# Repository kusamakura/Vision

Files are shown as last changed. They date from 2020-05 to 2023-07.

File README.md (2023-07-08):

# Vision Alt PCB

A PCB for the [Vision keyboard by SatT Keyboards](https://github.com/satt99/Vision) with alternative layout options.

## Notable changes

- R2 2U Backspace
- Left bottom row: from 2U-1U to 1U-2U, add 3U
- Right bottom row: remove 1U-1.75U, add 2.75U
- Nudge P position 0.125 mm to the left

## Layout

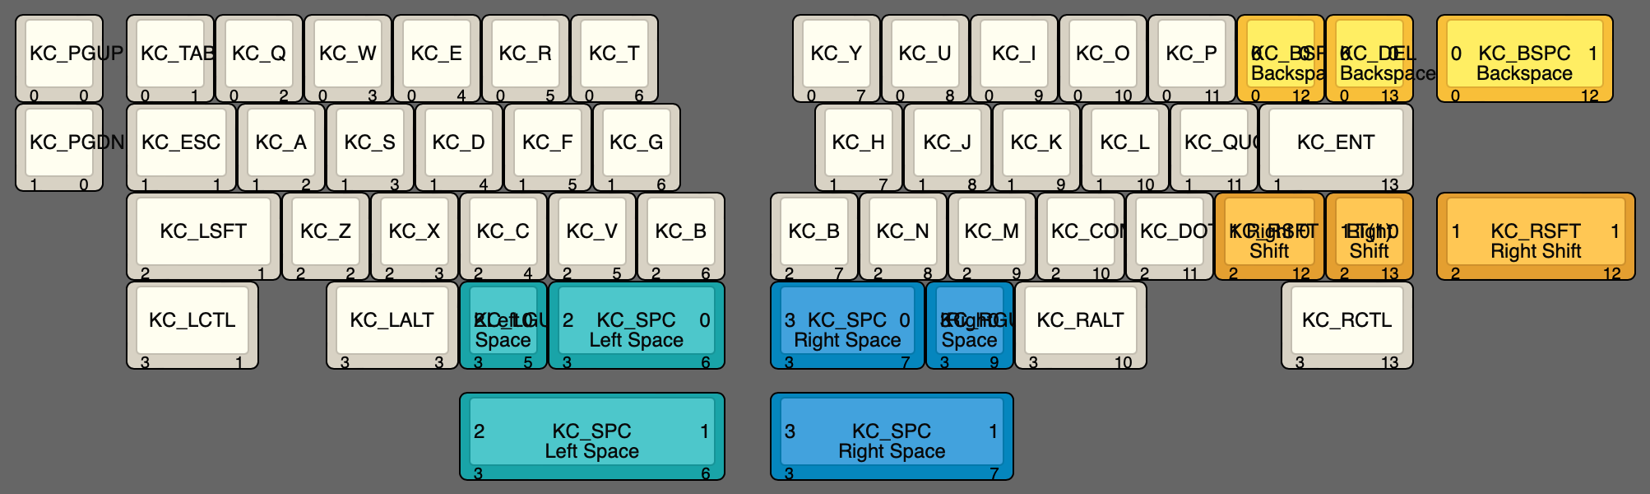
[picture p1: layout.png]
Layout


## How to use

Use the gerbers, BOM, and CPL files in the [JLCPCB production files folder](./JLCPCB/production_files/). **Set the PCB thickness to 1.2 mm when ordering**; otherwise your PCB will not work with the case.

Prototypes pending to check if this works.

The source files were originally in KiCAD 5, converted to KiCAD 6, then modified.
JLC production output was generated with the [JLC Fabrication Toolkit plugin](https://github.com/bennymeg/JLC-Plugin-for-KiCad).

## Disclaimer

Maintainers and contributors are not liable if you end up with a non-functional PCB. Order at your own risk. Support will not be provided but pull requests will be reviewed and possibly accepted.

## Todo

- [x] Finalize layout changes
- [x] Order prototypes
- [ ] Confirm prototypes
- [ ] Order plates
- [ ] Write firmware

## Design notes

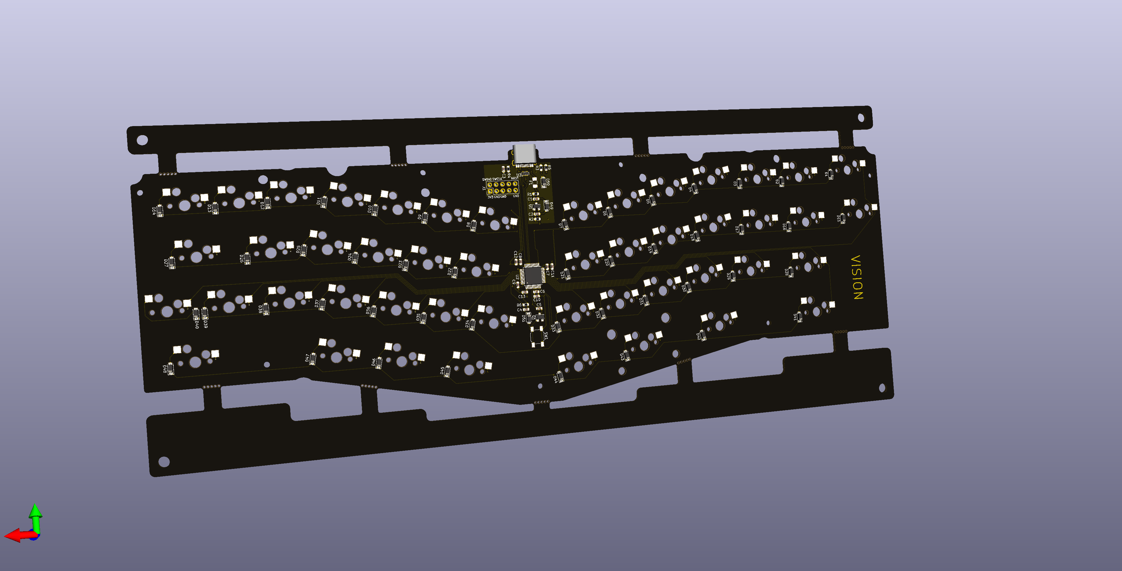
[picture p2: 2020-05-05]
Renders/Vision.png

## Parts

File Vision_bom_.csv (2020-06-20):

Component | Description | Part | References | Value | Footprint | Quantity Per PCB | Datasheet
1 | Unpolarized capacitor, small symbol | C_Small | C7 C8 C9 C13 | 100nF | C_0603_1608Metric | 4
2 | Unpolarized capacitor, small symbol | C_Small | C6 | 10nF | C_0603_1608Metric | 1
3 | Unpolarized capacitor, small symbol | C_Small | C4 | 10uF | C_0603_1608Metric | 1 | ~
4 | Unpolarized capacitor, small symbol | C_Small | C1 C2 C10 | 1uF | C_0603_1608Metric | 3 | ~
5 | Unpolarized capacitor, small symbol | C_Small | C3 | 4.7nF | C_0603_1608Metric | 1 | ~
6 | Unpolarized capacitor, small symbol | C_Small | C5 C11 C12 | 4.7uF | C_0603_1608Metric | 3 | ~
7 | Diode, small symbol | D_Small | D1 D2 D3 D4 D5 D6 D7 D8 D9 D10 D11 D12 D13 D14 D15 D16 D17 D18 D19 D20 D21 D22 D23 D24 D25 D26 D27 D28 D29 D30 D31 D32 D33 D34 D35 D36 D37 D38 D39 D40 D41 D42 D43 D44 D45 D46 D47 D48 D51 | 1N4148W | D_SOD-123 | 49
8 | Schottky diode, small symbol | D_Schottky_Small | D49 | BAT41ZFILM | D_SOD-123 | 1 | ~
9 | Bidirectional transient-voltage-suppression diode | D_TVS | D50 | SMF9.0CA | D_SOD-123 | 1 | ~
10 | Resettable fuse, polymeric positive temperature coefficient, small symbol | Polyfuse_Small | F1 | 500mA | Fuse_1206_3216Metric | 1
11 | Cortex Debug Connector, standard ARM Cortex-M SWD and JTAG interface | Conn_ARM_JTAG_SWD_10 | J1 | Conn_ARM_JTAG_SWD_10 | PinHeader_2x05_P2.54mm_Vertical | 1 | http://infocenter.arm.com/help/topic/com.arm.doc.ddi0314h/DDI0314H_coresight_components_trm.pdf
12 | Digital NPN Transistor, 2k2/47k, SOT-23 | DTC123J | Q1 | DTC123J | SOT-23 | 1
13 | Resistor, small symbol | R_Small | R1 R2 R6 | 100k | R_0603_1608Metric | 3 | ~
14 | Resistor, small symbol | R_Small | R4 | 1M | R_0603_1608Metric | 1 | ~
15 | Resistor, small symbol | R_Small | R3 R5 | 5.1k | R_0603_1608Metric | 2
16 | Push button switch, generic, two pins | SW_Push | SW1 | SW_Push | SW_SPST_SKQG_WithoutStem | 1
17 | 250mA Low Quiscent Current LDO, 3.0V output, SOT-23 | MCP1700-3002E_SOT23 | U1 | MCP1700-3002E_SOT23 | SOT-23 | 1 | http://ww1.microchip.com/downloads/en/DeviceDoc/20001826C.pdf
18 | ARM Cortex-M0 MCU, 128KB flash, 16KB RAM, 48MHz, 2-3.6V, 37 GPIO, LQFP-48 | STM32F072CBTx | U2 | STM32F072CBUx | LQFP-48_7x7mm_P0.5mm | 1 | http://www.st.com/st-web-ui/static/active/en/resource/technical/document/datasheet/DM00090510.pdf
19 |  | TPD4E05U06DQAR | U3 | TPD4E05U06DQAR | USON-TPDxE05U06 | 1
20 |  | HRO-TYPE-C-31-M-12 | USB1 | HRO-TYPE-C-31-M-12 | HRO-TYPE-C-31-M-12-Assembly | 1
Component Groups: | 20
Component Count: | 78
Fitted Components: | 78
Number of PCBs: | 1
Total components: | 78
Schematic Version:
Schematic Date:
PCB Variant: | default
BoM Date: | 2020/06/13 17:00:34
Schematic Source: | Vision.sch
KiCad Version: | Eeschema (5.1.4)-1

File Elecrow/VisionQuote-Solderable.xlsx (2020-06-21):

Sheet: PCB Specification
Vision PCB Solderable Specification
PCB Quantity | 30pcs
Layer | 2layer
PCB Thickness | 1.2mm
Dimensions | 299.5 mm * 124.3 mm
Castellated Hole | No
PCB Color | Black
Surface Finish | Immersoin gold
Copper Weight | 1oz
Text Color | White
Different Design | 1
Please find more PCB information on our on-line PCB ordering Page
https://www.elecrow.com/pcb-manufacturing.html

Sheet: BOM
VISION PCB
# | Reference | QTY | Value | Package | Manufacturer Part number | Description | SMD | THT | Original | Elecrow PN | Note | LCSC Link | Digikey Link | KBDFans Link
1 | C7 C8 C9 C13 | 4 | 100nF | C_0603_1608Metric | GCM188R71H104KA57D | Ceramic Capacitor | 8 |  | Y |  |  | https://lcsc.com/product-detail/Multilayer-Ceramic-Capacitors-MLCC-SMD-SMT_muRata_GCM188R71H104KA57D_100nF-104-10-50V-Car-level_C85864.html
2 | C6 | 1 | 10nF | C_0603_1608Metric | GRM188R71H103KA01D | Ceramic Capacitor | 2 |  | Y |  |  | https://lcsc.com/product-detail/Multilayer-Ceramic-Capacitors-MLCC-SMD-SMT_muRata_GRM188R71H103KA01D_10nF-103-10-50V_C77053.html
3 | C4 | 1 | 10uF | C_0603_1608Metric | GRM188R61E106KA73D | Ceramic Capacitor | 2 |  | Y |  |  | https://lcsc.com/product-detail/Others_Murata-Electronics-GRM188R61E106KA73D_C344022.html
4 | C1 C2 C10 | 3 | 1uF | C_0603_1608Metric | GRM188R61H105KAALD | Ceramic Capacitor | 6 |  | Y |  |  | https://lcsc.com/product-detail/Multilayer-Ceramic-Capacitors-MLCC-SMD-SMT_muRata_GRM188R61H105KAALD_1uF-105-10-50V_C77386.html
5 | C3 | 1 | 4.7nF | C_0603_1608Metric | GCJ188R71H472KA01D | Ceramic Capacitor | 2 |  | Y |  |  | https://lcsc.com/product-detail/Others_Murata-Electronics-GCJ188R71H472KA01D_C354387.html
6 | C5 C11 C12 | 3 | 4.7uF | C_0603_1608Metric | GRM188R61E475KE15D | Ceramic Capacitor | 6 |  | Y |  |  | https://lcsc.com/product-detail/Multilayer-Ceramic-Capacitors-MLCC-SMD-SMT_Murata-Electronics-GRM188R61E475KE15D_C408137.html
7 | D49 | 1 | BAT41ZFILM | D_SOD-123 | BAT41ZFILM | Diode, standard or schottky | 2 |  | Y |  |  | https://lcsc.com/product-detail/Schottky-Barrier-Diodes-SBD_STMicroelectronics-BAT41ZFILM_C222251.html
8 | D50 | 1 | SMF9.0CA | D_SOD-123 | SMF9.0CA | Bidirectional transient-voltage-suppression diode | 2 |  | Y |  |  | https://lcsc.com/product-detail/TVS_MDD-Microdiode-Electronics-SMF9-0CA_C123799.html
9 | D1 D2 D3 D4 D5 D6 D7 D8 D9 D10 D11 D12 D13 D14 D15 D16 D17 D18 D19 D20 D21 D22 D23 D24 D25 D26 D27 D28 D29 D30 D31 D32 D33 D34 D35 D36 D37 D38 D39 D40 D41 D42 D43 D44 D45 D46 D47 D48 D51 | 49 | SOD-123 | D_SOD-123 | 1N4148W | Diode, standard or schottky | 98 |  | Y |  |  | https://lcsc.com/product-detail/Switching-Diode_ST-Semtech-1N4148W_C81598.html
10 | F1 | 1 | 500mA | Fuse_1206_3216Metric | 1206L050/15YR | PTC Polyfuse Resettable, 500mA Hold, 1A Trip | 2 |  | Y |  |  | https://lcsc.com/product-detail/PTC-Resettable-Fuses_Littelfuse-1206L050-15YR_C151162.html
12 | Q1 | 1 | DTC123J | SOT-23 | DTC123JKAT146 | Digital NPN Transistor, 2k2/47k, SOT-23 | 3 |  | Y |  |  | https://lcsc.com/product-detail/Transistors-NPN-PNP_ROHM-Semicon-DTC123JKAT146_C111724.html
13 | R1 R2 R6 | 3 | 100k | R_0603_1608Metric | ESR03EZPJ104 | Resistor | 6 |  | Y |  |  | https://lcsc.com/product-detail/Others_ROHM-Semicon_ESR03EZPJ104_ROHM-Semicon-ESR03EZPJ104_C253331.html
14 | R4 | 1 | 1M | R_0603_1608Metric | ESR03EZPJ105 | Resistor | 2 |  | Y |  |  | https://lcsc.com/product-detail/Others_ROHM-Semicon_ESR03EZPJ105_ROHM-Semicon-ESR03EZPJ105_C253332.html
15 | R3 R5 | 2 | 5.1k | R_0603_1608Metric | ERJ3RBD5101V | Resistor | 4 |  | Y |  |  | https://lcsc.com/product-detail/Chip-Resistor-Surface-Mount_PANASONIC-ERJ-3RBD5101V_C191782.html
16 | SW1 | 1 | SW_Push | SKQGADE010 | SKQGADE010 | 5.2mm SMD Push Button, 4 pads | 4 |  | Y |  |  | https://lcsc.com/product-detail/Tactile-Switches_ALPS-Electric-SKQGADE010_C116647.html
17 | U1 | 1 | MCP1700-3002E_SOT23 | SOT-23 | MCP1700T-3002E/TT | 250mA Low Quiscent Current LDO, 3.0V output, SOT-23 | 3 |  | Y |  |  | https://lcsc.com/product-detail/Low-Dropout-Regulators-LDO_Microchip-Tech-MCP1700T-3002E-TT_C62244.html
18 | U2 | 1 | STM32F072CBT6 | LQFP-48_7x7mm_P0.5mm | STM32F072CBT6 | STM32F072CBT6 (LQFP-48, 0.5mm Pitch) | 48 |  | Y |  | IF parts are not in stock at LCSC, use Digi-key | https://lcsc.com/product-detail/ST-Microelectronics_STMicroelectronics-STM32F072CBT6_C81720.html | https://www.digikey.jp/product-detail/ja/stmicroelectronics/STM32F072CBT6/497-14645-ND/4815292
19 | U3 | 1 | TPD4E05U06DQAR | 10-USON | TPD4E05U06DQAR | ESD Protection Diode Package | 10 |  | Y |  |  | https://lcsc.com/product-detail/Diodes-ESD_Texas-Instruments_TPD4E05U06DQAR_Texas-Instruments-Texas-Instruments-TPD4E05U06DQAR_C138714.html
20 | USB1 | 1 | HRO-TYPE-C-31-M-12 | HRO-TYPE-C-31-M-12-Assembly | TYPE-C-31-M-12 | USB Type-C Connector | 12 | 4 | Y |  |  | https://lcsc.com/product-detail/USB-Connectors_Korean-Hroparts-Elec-TYPE-C-31-M-12_C165948.html
 | Declare：
 | 1、If the component should be original like Digi-key or Mouser，the component must have complete Manufacture part number

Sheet: Parts Mapping
Please see file VISION_PCB_PRINT.pdf

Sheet: Position File
Please see file vision-bottom.pos

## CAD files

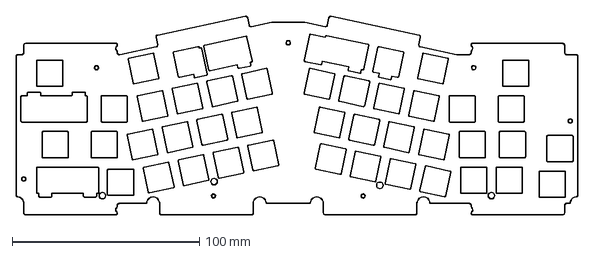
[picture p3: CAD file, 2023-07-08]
plate/alt-plate-noeafspring.dxf
300.2 x 106.1 mm

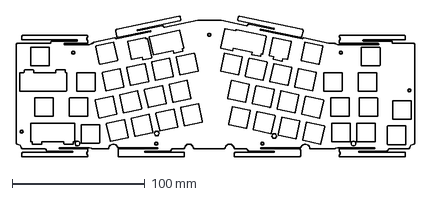
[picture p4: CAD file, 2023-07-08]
plate/alt-plate-leafspring.dxf
300.2 x 106.1 mm

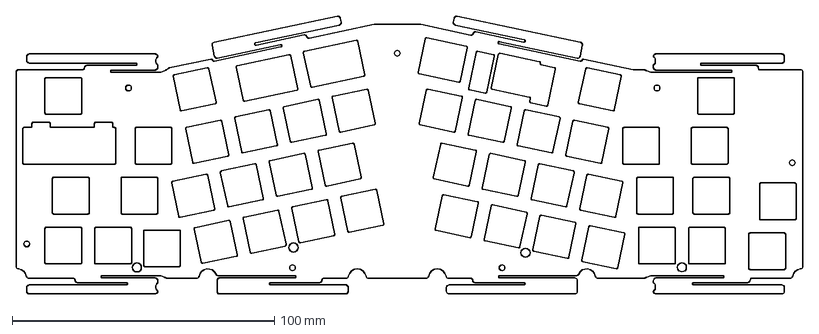
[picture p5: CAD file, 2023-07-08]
plate/og-plate-leafspring-r2.dxf
300.2 x 106.1 mm

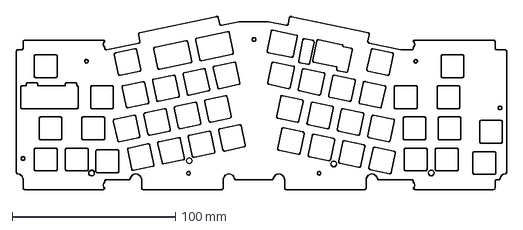
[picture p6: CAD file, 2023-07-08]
plate/og-plate-noleafspring-r2.dxf
300.2 x 106.1 mm

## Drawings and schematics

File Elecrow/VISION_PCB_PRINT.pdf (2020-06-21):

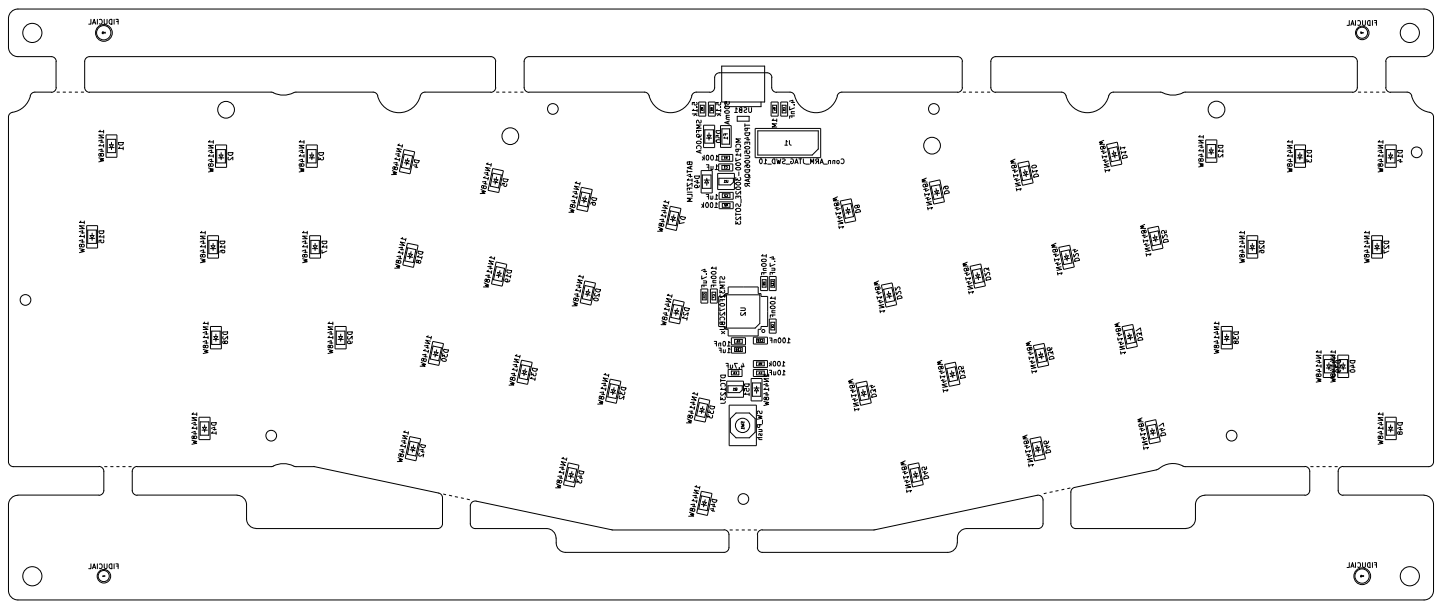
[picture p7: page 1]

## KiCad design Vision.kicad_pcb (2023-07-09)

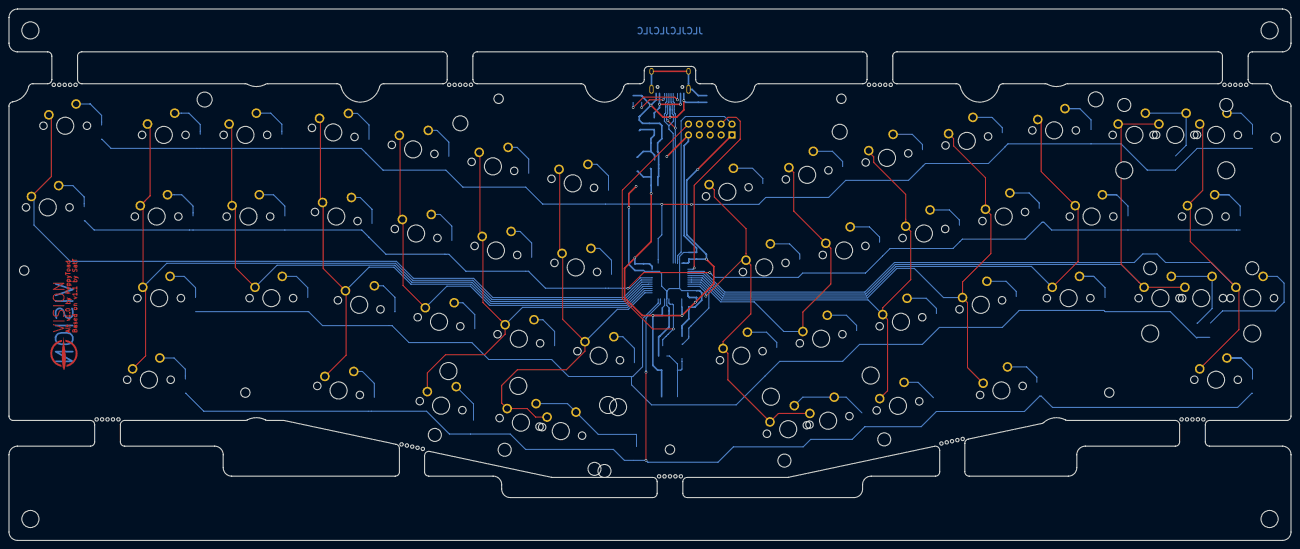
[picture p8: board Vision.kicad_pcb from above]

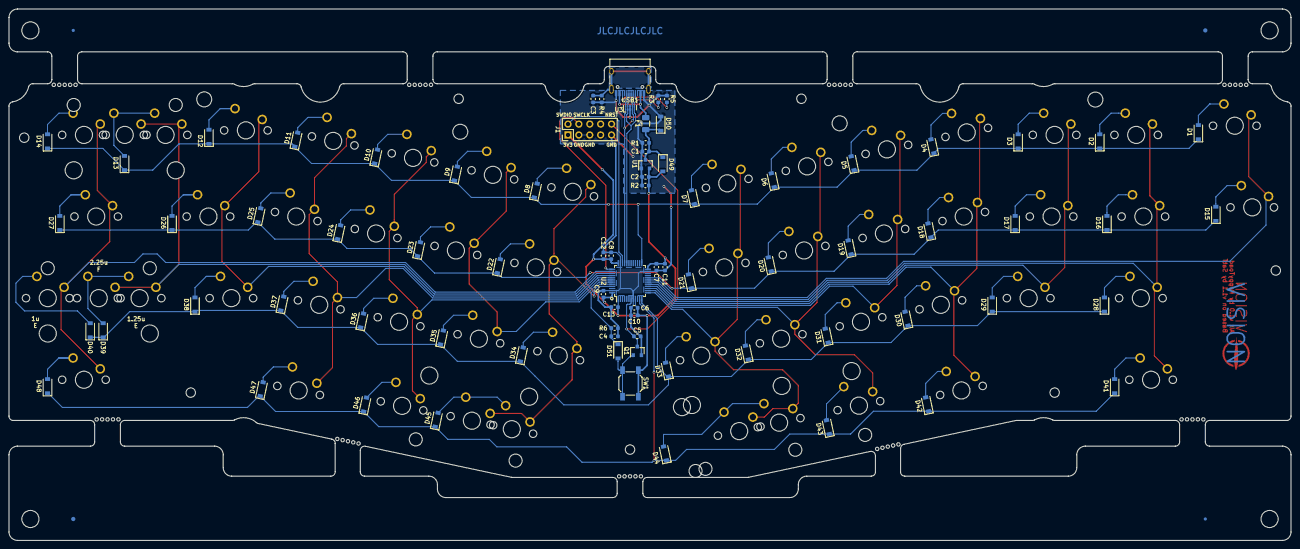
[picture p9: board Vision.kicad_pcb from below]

Board: 2 copper layers, 299.2 x 124.0 mm, 145 parts (83 on the bottom side), 77 nets.

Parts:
C1, C2, C10: 1uF; C_0603_1608Metric
C3: 4.7nF; C_0603_1608Metric
C4: 10uF; C_0603_1608Metric
C5, C11, C12: 4.7uF; C_0603_1608Metric
C6: 10nF; C_0603_1608Metric
C7, C8, C9, C13: 100nF; C_0603_1608Metric
D1, D2, D3, D4, D5, D6, D7, D8, D9, D10, D11, D12, D13, D14, D15, D16, D17, D18, D19, D20, D21, D22, D23, D24, D25, D26, D27, D28, D29, D30, D31, D32, D33, D34, D35, D36, D37, D38, D39, D40, D41, D42, D43, D44, D45, D46, D47, D48, D51: 1N4148W; D_SOD-123
D49: BAT41ZFILM; D_SOD-123
D50: SMF9.0CA; D_SOD-123
F1: 500mA; Fuse_1206_3216Metric
H1: LOGO1; logo1
H2: LOGO2; logo2
H3, H4: FIDUCIAL; Fiducial_0.75mm_Mask2.25mm
H5, H6: FIDUCIAL; Fiducial_1mm_Mask3mm
H7, H8, H9, H10, H11, H12, H13, H14, H15: MOUSEBITES; breakaway-mousebites
J1: Conn_ARM_JTAG_SWD_10; PinHeader_2x05_P2.54mm_Vertical
K_,1: MX-1U; MXOnly-1U-NoLED
K_.1: MX-1U; MXOnly-1U-NoLED
K_;1: MX-1U; MXOnly-1U-NoLED
K_A1: MX-1U; MXOnly-1U-NoLED
K_ALT1, K_ALT2: MX-1.5U; MXOnly-1.5U-NoLED
K_B1, K_B2: MX-1U; MXOnly-1U-NoLED
K_BSPC1: MX-1U; MXOnly-1U-NoLED
K_BSPC2: MX-2U; MXOnly-2U-NoLED
K_C1: MX-1U; MXOnly-1U-NoLED
K_CTRL1, K_CTRL2: MX-1.5U; MXOnly-1.5U-NoLED
K_D1: MX-1U; MXOnly-1U-NoLED
K_DEL1: MX-1U; MXOnly-1U-NoLED
K_E1: MX-1U; MXOnly-1U-NoLED
K_ENTER1: MX-1.75U; MXOnly-1.75U-NoLED
K_ESC1: MX-1U; MXOnly-1U-NoLED
K_F1: MX-1U; MXOnly-1U-NoLED
K_FN1: MX-1U; MXOnly-1U-NoLED
K_G1: MX-1U; MXOnly-1U-NoLED
K_H1: MX-1U; MXOnly-1U-NoLED
K_I1: MX-1U; MXOnly-1U-NoLED
K_J1: MX-1U; MXOnly-1U-NoLED
K_K1: MX-1U; MXOnly-1U-NoLED
K_L1: MX-1U; MXOnly-1U-NoLED
K_M1: MX-1U; MXOnly-1U-NoLED
K_N1: MX-1U; MXOnly-1U-NoLED
K_O1: MX-1U; MXOnly-1U-NoLED
K_P1: MX-1U; MXOnly-1U-NoLED
K_PGDN1: MX-1U; MXOnly-1U-NoLED
K_PGUP1: MX-1U; MXOnly-1U-NoLED
K_Q1: MX-1U; MXOnly-1U-NoLED
K_R1: MX-1U; MXOnly-1U-NoLED
K_S1: MX-1U; MXOnly-1U-NoLED
K_SHIFT1: MX-1.75U; MXOnly-1.75U-NoLED
K_SHIFT2: MX-1.25U; MXOnly-1.25U-NoLED
K_SHIFT3: MX-2.25U; MXOnly-2.25U-NoLED
K_SPC1: MX-2U; MXOnly-2U-ReversedStabilizers-NoLED
K_SPC2: MX-1.75U; MXOnly-1.75U-NoLED
K_SPC3: MX-3U; MXOnly-3U-ReversedStabilizers-NoLED
K_SPC4: MX-2.75U; MXOnly-2.75U-ReversedStabilizers-NoLED
K_T1: MX-1U; MXOnly-1U-NoLED
K_TAB1: MX-1.25U; MXOnly-1.25U-NoLED
K_U1: MX-1U; MXOnly-1U-NoLED
K_V1: MX-1U; MXOnly-1U-NoLED
K_W1: MX-1U; MXOnly-1U-NoLED
K_WIN1, K_WIN2: MX-1U; MXOnly-1U-NoLED
K_X1: MX-1U; MXOnly-1U-NoLED
K_Y1: MX-1U; MXOnly-1U-NoLED
K_Z1: MX-1U; MXOnly-1U-NoLED
Q1: DTC123J; SOT-23
R1, R2, R6: 100k; R_0603_1608Metric
R3, R5: 5.1k; R_0603_1608Metric
R4: 1M; R_0603_1608Metric
SW1: SW_Push; SW_SPST_SKQG_WithoutStem
U1: MCP1700-3002E_SOT23; SOT-23
U2: STM32F072CBUx; LQFP-48_7x7mm_P0.5mm
U3: TPD4E05U06DQAR; USON-TPDxE05U06
USB1: HRO-TYPE-C-31-M-12; USB_C_Receptacle_HRO_TYPE-C-31-M-12

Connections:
+3V3: C2.1, C6.1, C7.1, C8.1, C9.1, C10.1, C11.1, C12.1, C13.1, D49.2 (A), J1.1 (VTref), R2.2, SW1.1, U1.2 (VO), U2.1 (VBAT), U2.9 (VDDA), U2.24 (VDD), U2.36 (VDDIO2), U2.48 (VDD)
+5V: C1.1, D49.1 (K), D50.1 (A1), F1.1, R1.2, U1.3 (VI)
BOOT0: C4.1, D51.1 (K), R6.2, U2.44 (BOOT0)
COL0: K_PGDN1.1 (COL), K_PGUP1.1 (COL), U2.19 (PB1)
COL1: K_CTRL1.1 (COL), K_ESC1.1 (COL), K_SHIFT1.1 (COL), K_TAB1.1 (COL), U2.18 (PB0)
COL2: K_A1.1 (COL), K_Q1.1 (COL), K_Z1.1 (COL), U2.17 (PA7)
COL3: K_ALT1.1 (COL), K_S1.1 (COL), K_W1.1 (COL), K_X1.1 (COL), U2.16 (PA6)
COL4: K_C1.1 (COL), K_D1.1 (COL), K_E1.1 (COL), U2.15 (PA5)
COL5: K_F1.1 (COL), K_R1.1 (COL), K_V1.1 (COL), K_WIN1.1 (COL), U2.14 (PA4)
COL6: K_B1.1 (COL), K_G1.1 (COL), K_SPC1.1 (COL), K_SPC3.1 (COL), K_T1.1 (COL), U2.13 (PA3)
COL7: K_B2.1 (COL), K_H1.1 (COL), K_SPC2.1 (COL), K_SPC4.1 (COL), K_Y1.1 (COL), U2.45 (PB8)
COL8: K_J1.1 (COL), K_N1.1 (COL), K_U1.1 (COL), U2.43 (PB7)
COL9: K_I1.1 (COL), K_K1.1 (COL), K_M1.1 (COL), K_WIN2.1 (COL), U2.42 (PB6)
COL10: K_,1.1 (COL), K_ALT2.1 (COL), K_L1.1 (COL), K_O1.1 (COL), U2.41 (PB5)
COL11: K_.1.1 (COL), K_;1.1 (COL), K_P1.1 (COL), U2.40 (PB4)
COL12: K_BSPC1.1 (COL), K_BSPC2.1 (COL), K_SHIFT2.1 (COL), K_SHIFT3.1 (COL), U2.39 (PB3)
COL13: K_CTRL2.1 (COL), K_DEL1.1 (COL), K_ENTER1.1 (COL), K_FN1.1 (COL), U2.38 (PA15)
D+: U2.33 (PA12), U3.1 (D1+), U3.4 (D2+), U3.7 (NC), U3.10 (NC)
D-: U2.32 (PA11), U3.2 (D1-), U3.5 (D2-), U3.6 (NC), U3.9 (NC)
GND: C1.2, C2.2, C3.1, C4.2, C5.2, C6.2, C7.2, C8.2, C9.2, C10.2, C11.2, C12.2, C13.2, D50.2 (A2), J1.3 (GND), J1.5 (GND), J1.9 (GNDDetect), Q1.2 (E), R1.1, R2.1, R3.1, R4.1, R5.1, R6.1, U1.1 (GND), U2.8 (VSSA), U2.23 (VSS), U2.35 (VSS), U2.47 (VSS), U3.3 (GND), U3.8 (GND)
NRST: C5.1, J1.10 (~RESET), Q1.3 (C), U2.7 (NRST)
unnamed: C3.2, R4.2, USB1.S1
unnamed: D1.2 (A), K_PGUP1.2 (ROW)
unnamed: D2.2 (A), K_ESC1.2 (ROW)
unnamed: D3.2 (A), K_Q1.2 (ROW)
unnamed: D4.2 (A), K_W1.2 (ROW)
unnamed: D5.2 (A), K_E1.2 (ROW)
unnamed: D6.2 (A), K_R1.2 (ROW)
unnamed: D7.2 (A), K_T1.2 (ROW)
unnamed: D8.2 (A), K_Y1.2 (ROW)
unnamed: D9.2 (A), K_U1.2 (ROW)
unnamed: D10.2 (A), K_I1.2 (ROW)
unnamed: D11.2 (A), K_O1.2 (ROW)
unnamed: D12.2 (A), K_P1.2 (ROW)
unnamed: D13.2 (A), K_BSPC1.2 (ROW), K_BSPC2.2 (ROW)
unnamed: D14.2 (A), K_DEL1.2 (ROW)
unnamed: D15.2 (A), K_PGDN1.2 (ROW)
unnamed: D16.2 (A), K_TAB1.2 (ROW)
unnamed: D17.2 (A), K_A1.2 (ROW)
unnamed: D18.2 (A), K_S1.2 (ROW)
unnamed: D19.2 (A), K_D1.2 (ROW)
unnamed: D20.2 (A), K_F1.2 (ROW)
unnamed: D21.2 (A), K_G1.2 (ROW)
unnamed: D22.2 (A), K_H1.2 (ROW)
unnamed: D23.2 (A), K_J1.2 (ROW)
unnamed: D24.2 (A), K_K1.2 (ROW)
unnamed: D25.2 (A), K_L1.2 (ROW)
unnamed: D26.2 (A), K_;1.2 (ROW)
unnamed: D27.2 (A), K_ENTER1.2 (ROW)
unnamed: D28.2 (A), K_SHIFT1.2 (ROW)
unnamed: D29.2 (A), K_Z1.2 (ROW)
unnamed: D30.2 (A), K_X1.2 (ROW)
unnamed: D31.2 (A), K_C1.2 (ROW)
unnamed: D32.2 (A), K_V1.2 (ROW)
unnamed: D33.2 (A), K_B1.2 (ROW)
unnamed: D34.2 (A), K_B2.2 (ROW)
unnamed: D35.2 (A), K_N1.2 (ROW)
unnamed: D36.2 (A), K_M1.2 (ROW)
unnamed: D37.2 (A), K_,1.2 (ROW)
unnamed: D38.2 (A), K_.1.2 (ROW)
unnamed: D39.2 (A), K_SHIFT2.2 (ROW), K_SHIFT3.2 (ROW)
unnamed: D40.2 (A), K_FN1.2 (ROW)
unnamed: D41.2 (A), K_CTRL1.2 (ROW)
unnamed: D42.2 (A), K_ALT1.2 (ROW)
unnamed: D43.2 (A), K_WIN1.2 (ROW)
unnamed: D44.2 (A), K_SPC1.2 (ROW), K_SPC3.2 (ROW)
unnamed: D45.2 (A), K_SPC2.2 (ROW), K_SPC4.2 (ROW)
unnamed: D46.2 (A), K_WIN2.2 (ROW)
unnamed: D47.2 (A), K_ALT2.2 (ROW)
unnamed: D48.2 (A), K_CTRL2.2 (ROW)
unnamed: D51.2 (A), Q1.1 (B), SW1.2
ROW0: D1.1 (K), D2.1 (K), D3.1 (K), D4.1 (K), D5.1 (K), D6.1 (K), D7.1 (K), D8.1 (K), D9.1 (K), D10.1 (K), D11.1 (K), D12.1 (K), D13.1 (K), D14.1 (K), U2.25 (PB12)
ROW1: D15.1 (K), D16.1 (K), D17.1 (K), D18.1 (K), D19.1 (K), D20.1 (K), D21.1 (K), D22.1 (K), D23.1 (K), D24.1 (K), D25.1 (K), D26.1 (K), D27.1 (K), U2.20 (PB2)
ROW2: D28.1 (K), D29.1 (K), D30.1 (K), D31.1 (K), D32.1 (K), D33.1 (K), D34.1 (K), D35.1 (K), D36.1 (K), D37.1 (K), D38.1 (K), D39.1 (K), D40.1 (K), U2.12 (PA2)
ROW3: D41.1 (K), D42.1 (K), D43.1 (K), D44.1 (K), D45.1 (K), D46.1 (K), D47.1 (K), D48.1 (K), U2.11 (PA1)
SWCLK: J1.4 (SWDCLK/TCK), U2.37 (PA14)
SWDIO: J1.2 (SWDIO/TMS), U2.34 (PA13)

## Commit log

2020-05-02 Rename project
    [Vision.kicad_pcb, Vision.sch, Vision_bom_.csv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]
2020-05-03 Update schematics
    [Vision.sch]
2020-05-03 Set switch position
    [Vision.kicad_pcb, Vision.sch, switch_position.csv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]
2020-05-04 Fix switch position
    [Vision.kicad_pcb, switch_position.csv, switch_position_raw.csv]
2020-05-05 Route PCB
    [Vision-B_Cu.gbl, Vision-B_Fab.gbr, Vision-B_Mask.gbs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]
2020-05-05 Add edgerails
    [Vision-B_Cu.gbl, Vision-B_Fab.gbr, Vision-B_Mask.gbs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]
2020-05-05 Fix gerber
    [Vision-B_Cu.gbl, Vision-B_Fab.gbr, Vision-B_Mask.gbs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]
2020-05-06 Fix fiducials
    [Vision.kicad_pcb]
2020-05-06 Add BOM
    [Vision-B_Cu.gbl, Vision-B_Mask.gbs, Vision-B_Paste.gbp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]
2020-06-13 Update pcb shape
    [Vision-B_Cu.gbl, Vision-B_Mask.gbs, Vision-B_Paste.gbp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]
2020-06-13 Add files for Elecrow PCBA
    [Vision.kicad_pcb, Vision.sch, VisionQuote.xlsx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]
2020-06-20 Update Elecrow PCBA files
    [VisionQuote.xlsx, Vision_bom_.csv]
2020-06-20 Update revision number
    [Vision-B_Cu.gbl, Vision-B_Mask.gbs, Vision-B_Paste.gbp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]
2020-06-21 Fix routing
    [Vision-B_Cu.gbl, Vision-B_Mask.gbs, Vision-B_Paste.gbp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]
2020-06-21 Update PCB
    [Vision-B_Cu.gbl, Vision-B_Mask.gbs, Vision-B_Paste.gbp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]
2020-06-21 Add silk for different layouts
    [Vision-B_Cu.gbl, Vision-B_Mask.gbs, Vision-B_Paste.gbp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]
2020-06-21 Fix overlapping silk
    [Vision.kicad_pcb]
2023-02-14 Create alt rev 1 with JLC production files
    [BOM-Vision.csv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]
2023-07-08 Update BOM and CPL
    [BOM-Vision.csv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]
2023-07-08 Add plates and update readme
    [plate-leafspring-r2.dxf, plate-noleafspring-r2.dxf]
2023-07-08 Nudge P switch position to the left, add custom plates
    [Vision-B_Cu.gbl, Vision-B_Mask.gbs, Vision-B_Paste.gbp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]
2023-07-08 Update default gerber output dir
    [Vision.kicad_pcb]
2023-07-08 Fix footprints
    [Vision-B_Cu.gbl, Vision-B_Mask.gbs, Vision-B_Paste.gbp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]
2023-07-08 Use native Kicad USB-C footprint
    [BOM-Vision.csv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]
2023-07-09 Final pre-proto changes
    [BOM-Vision.csv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]
